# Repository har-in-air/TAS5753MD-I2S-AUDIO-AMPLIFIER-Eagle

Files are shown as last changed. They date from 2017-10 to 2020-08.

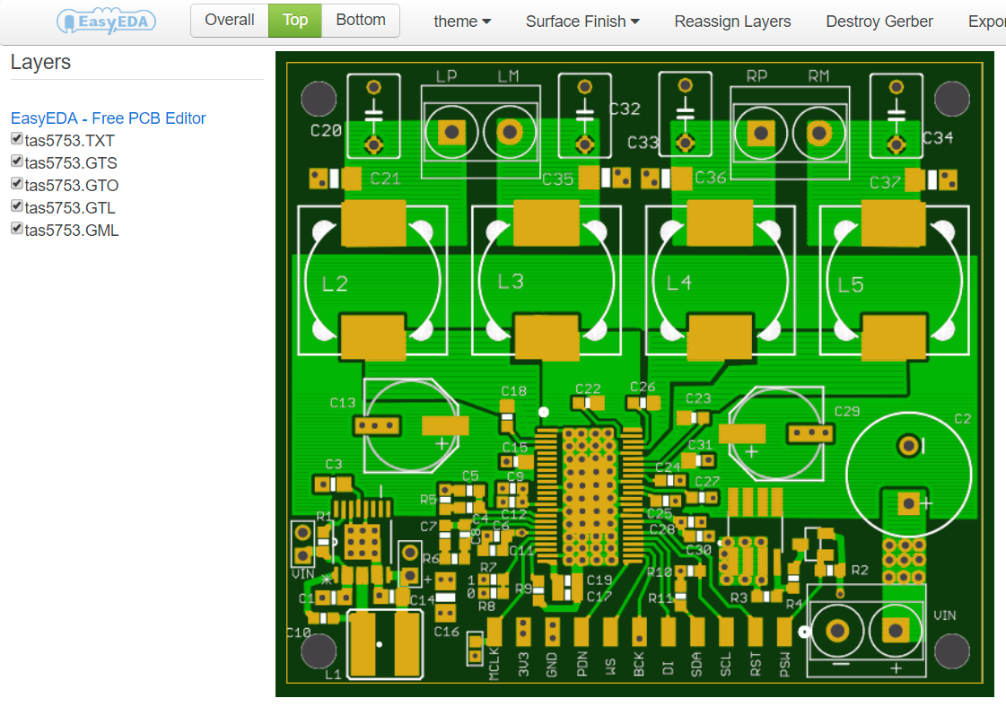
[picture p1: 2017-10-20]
layout_top.png

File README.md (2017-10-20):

# TAS5753MD-I2S-AUDIO-AMPLIFIER-Eagle
Digital audio power amplifier with I2S interface using TI's TAS5753MD chip

Eagle schematic, layout and gerber files

Uses Stereo Bridge Tied Load application schematic from the TI datasheet. Added an A04409 PMOSFET and BSS138 NMOSFET to allow controlled PVDD on/off. Added MAX16904 3.3V (max 600mA) switching regulator to power the TTL logic 3.3V supply - this can also be used to supply 3.3V to the driving circuit, e.g. Espressif ESP32 module with web radio or bluetooth speaker firmware.

Features : 
1. PVDD range is 4.5V to 24V
2. Can drive 4ohm speakers
3. 90% efficiency
4. 0.2%THD @ 10W rms/channel into 4ohms with PVDD = 12V
5. Requires external MCLK. However, if used with 44.1kHz or 48kHz sampling rates, and the bit clock (BCK / SCLK) is at least 64 x sampling rate, then MCLK can be tied to BCK. A solder jumper is provided for this. This is how I have tested the board.

## Components
See the datasheet for recommendations. The specific packages used in the layout are :

### Capacitors

1206 : C16, C21, C35, C36, C37

0805 : C1, C3, C14

0603 : remaining smt ceramic caps

### Resistors
All are 0603 package. R9 (18K) needs to be 1% precision. Either populate R7 OR R8 to set the LSb of the TAS5753MD I2C slave address. R4 (22K) should be shorted or replaced with a 0 ohm resistor if PVDD is less than 10V, to ensure that the PMOSFET fully turns on.

I found all the passive components on Aliexpress and Ebay. E.g.:

https://www.aliexpress.com/item/10pcs-lot-12-12-7-15UH-SMT-SMD-Patch-Shielding-Power-Inductors-150-Electronic-Components-Free/32591194870.html

https://www.aliexpress.com/item/10pcs-0-68uF-684J-100V-Free-shipping-CBB-Polypropylene-film-capacitor-pitch-5mm-684-100V-680nF/32712243979.html

https://www.aliexpress.com/item/100pcs-lot-100nF-X7R-Error-10-50V-0603-smd-capacitor/32318089455.html

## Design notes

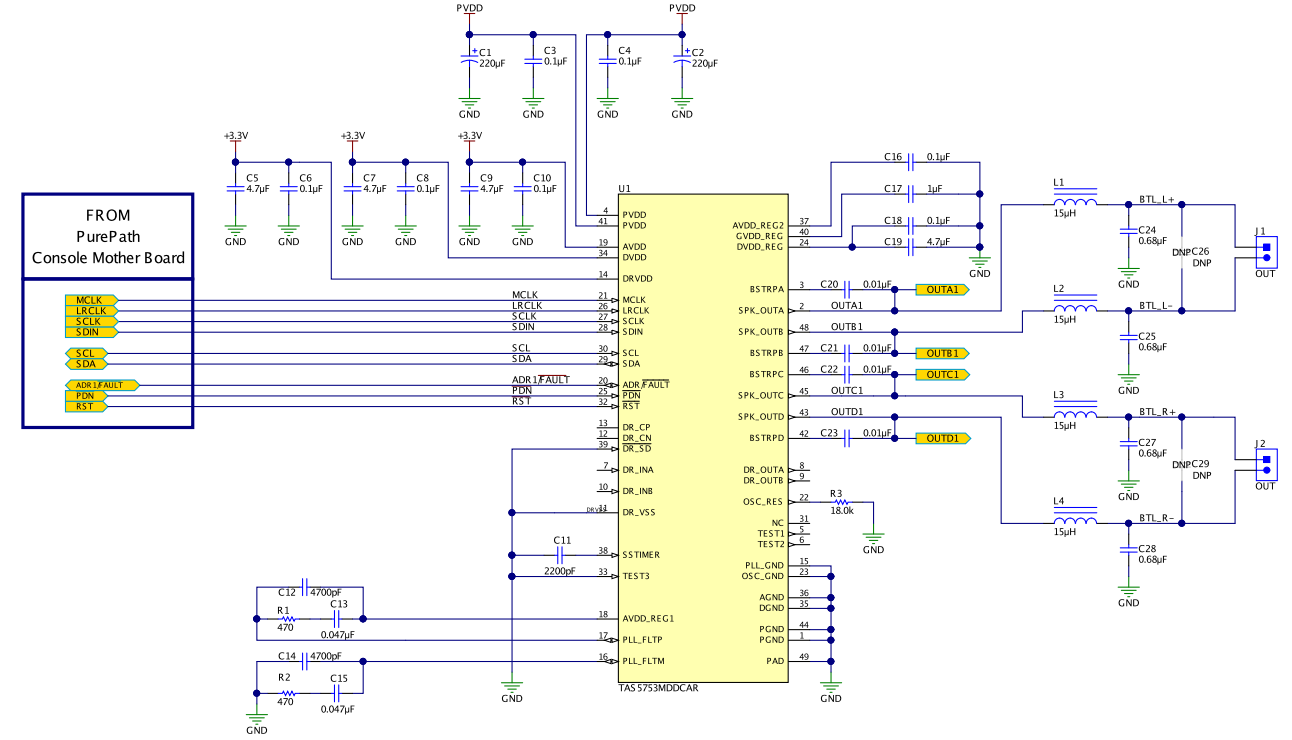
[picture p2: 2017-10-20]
datasheet_schematic.png

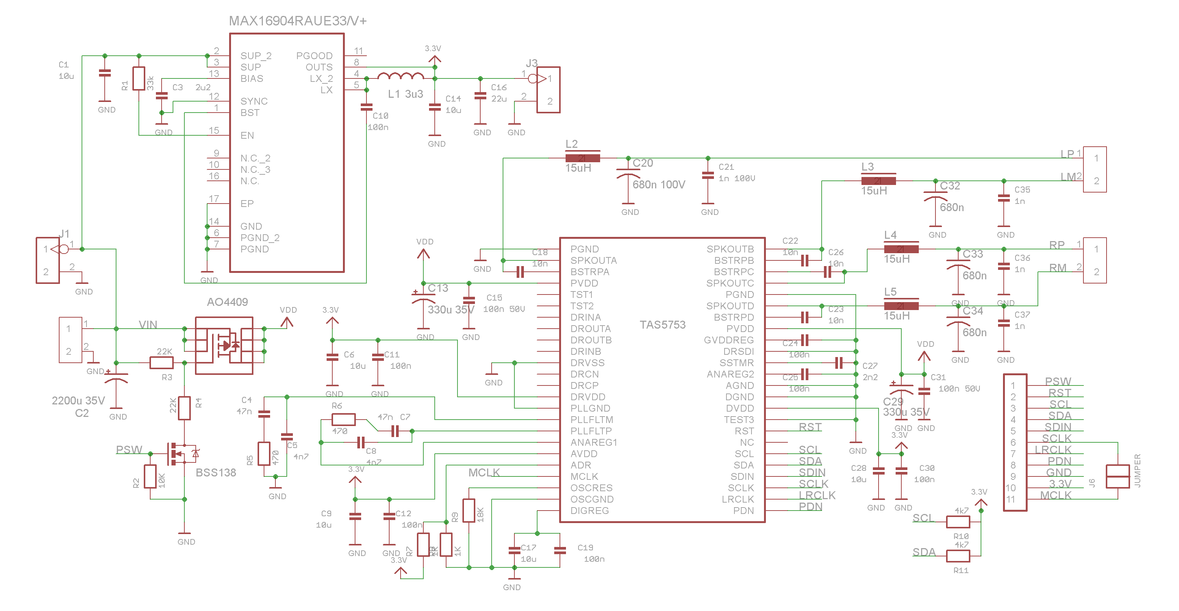
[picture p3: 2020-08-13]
tas5753_schematic.png

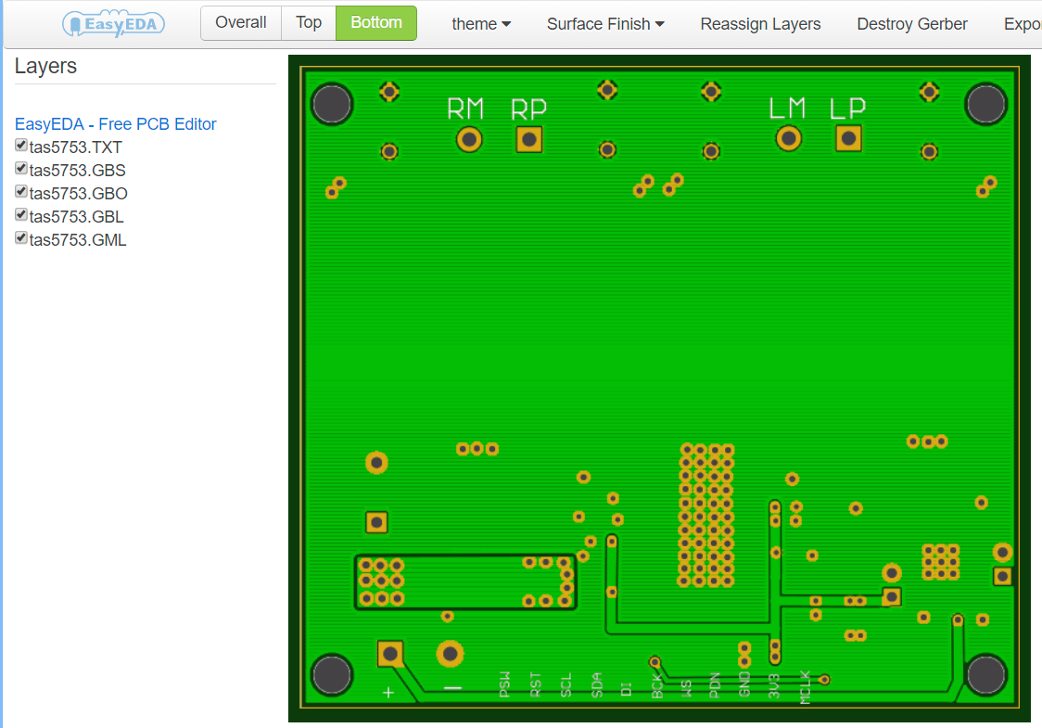
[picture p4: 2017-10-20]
layout_bottom.png

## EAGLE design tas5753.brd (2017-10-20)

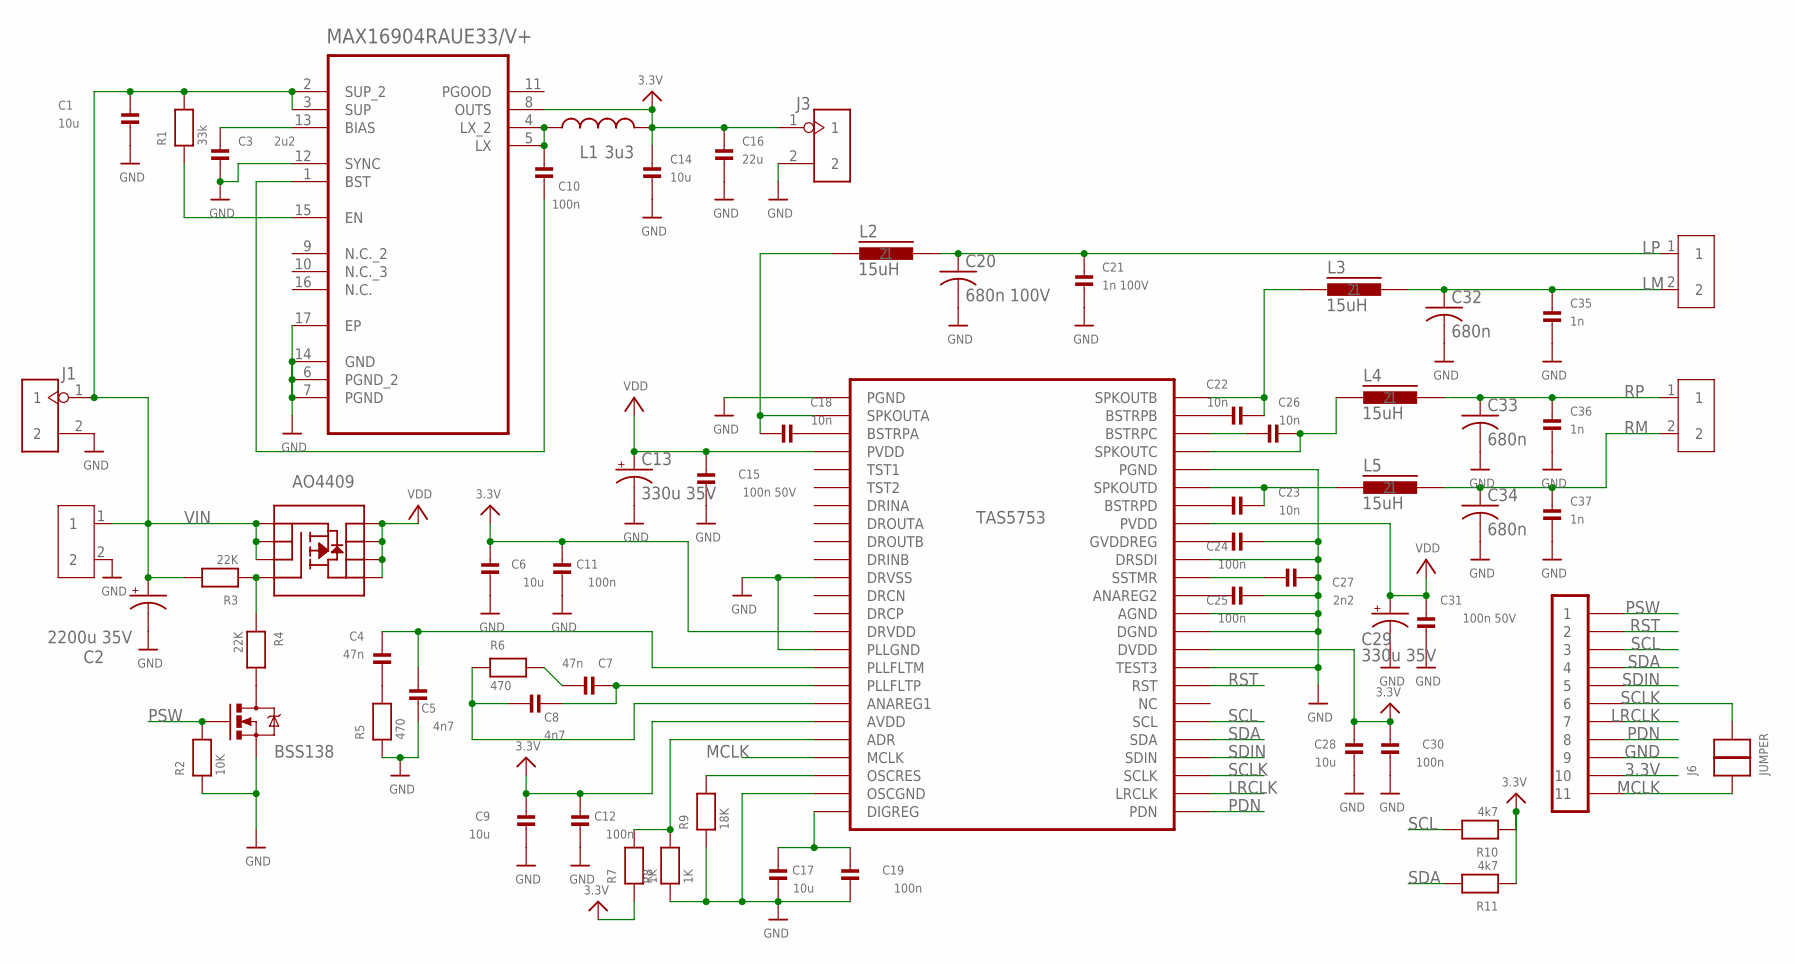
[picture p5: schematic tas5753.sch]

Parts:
C1, C14: 10u; 0805
C2: 2200u 35V; CPOL-RADIAL-1000UF-25V
C3: 2u2; 0805
C4, C7: 47n; 0603
C5, C8: 4n7; 0603
C6, C9, C17, C28: 10u; 0603
C10, C11, C12, C19, C24, C25, C30: 100n; 0603
C13, C29: 330u 35V; PANASONIC_E
C15, C31: 100n 50V; 0603
C16: 22u; 1206
C18, C22, C23, C26: 10n; 0603
C20: 680n 100V; C050-045X075
C21: 1n 100V; 1206
C27: 2n2; 0603
C32, C33, C34: 680n; C050-045X075
C35, C36, C37: 1n; 1206
IC1: AO4409; SO08
J1, J3: HEADER-2P-2.0; 2P-2.0
J2, J4, J5: SCREW-TERMINAL-2P'5.08'; 2P-5.08
J6: JUMPER
L1: 3u3; CR54
L2, L3, L4, L5: 15uH; DR125
P1: CONN_1X11_SMT_254; CONN_SMT_1X11_254
Q1: BSS138; SOT23
R1: 33k; 0603
R2: 10K; 0603
R3, R4: 22K; 0603
R5, R6: 470; 0603
R7, R8: 1K; 0603
R9: 18K; 0603
R10, R11: 4k7; 0603
U1: MAX16904RAUE33/V+; SOP65P638X110-17N
U2: TAS5753; HTSSOP_48

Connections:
3.3V: C6.1, C9.1, C11.1, C12.1, C14.1, C16.1, C28.1, C30.1, J3.1, L1.P$2 (2), P1.P$10 (10), R7.1, R10.1, R11.1, U1.8 (OUTS), U2.P$14 (DRVDD), U2.P$19 (AVDD), U2.P$34 (DVDD)
GND: C1.2, C2.2 (-), C3.2, C5.1, C6.2, C9.2, C11.2, C12.2, C13.-, C14.2, C15.1, C16.2, C17.2, C19.2, C20.2, C21.2, C24.2, C25.2, C27.2, C28.2, C29.-, C30.2, C31.1, C32.2, C33.2, C34.2, C35.2, C36.2, C37.2, J1.2, J2.2, J3.2, P1.P$9 (9), Q1.2 (S), R2.1, R5.1, R8.1, R9.1, U1.6 (PGND_2), U1.7 (PGND), U1.12 (SYNC), U1.14 (GND), U1.17 (EP), U2.P$1 (PGND), U2.P$11 (DRVSS), U2.P$15 (PLLGND), U2.P$23 (OSCGND), U2.P$33 (TEST3), U2.P$35 (DGND), U2.P$36 (AGND), U2.P$39 (DRSDI), U2.P$44 (PGND), U2.P$49 (PGND)
LM: C32.1, C35.1, J4.2, L3.2
LP: C20.1, C21.1, J4.1, L2.2
LRCLK: P1.P$7 (7), U2.P$26 (LRCLK)
MCLK: J6.1, P1.P$11 (11), U2.P$21 (MCLK)
unnamed: R9.2, U2.P$22 (OSCRES)
unnamed: C7.2, R6.2
unnamed: C18.2, U2.P$3 (BSTRPA)
unnamed: C7.1, C8.1, U2.P$17 (PLLFLTP)
unnamed: C26.1, U2.P$46 (BSTRPC)
unnamed: C22.1, U2.P$47 (BSTRPB)
unnamed: C22.2, L3.1, U2.P$48 (SPKOUTB)
unnamed: C26.2, L4.1, U2.P$45 (SPKOUTC)
unnamed: R7.2, R8.2, U2.P$20 (ADR)
unnamed: C4.1, R5.2
unnamed: C18.1, L2.1, U2.P$2 (SPKOUTA)
unnamed: C4.2, C5.2, U2.P$16 (PLLFLTM)
unnamed: C23.1, U2.P$42 (BSTRPD)
unnamed: C23.2, L5.1, U2.P$43 (SPKOUTD)
unnamed: C27.1, U2.P$38 (SSTMR)
unnamed: C25.1, U2.P$37 (ANAREG2)
unnamed: IC1.4 (G), R3.1, R4.1
unnamed: C24.1, U2.P$40 (GVDDREG)
unnamed: C10.1, L1.P$1 (1), U1.4 (LX_2), U1.5 (LX)
unnamed: C10.2, U1.1 (BST)
unnamed: C8.2, R6.1, U2.P$18 (ANAREG1)
unnamed: C3.1, U1.13 (BIAS)
unnamed: R1.1, U1.15 (EN)
unnamed: C17.1, C19.1, U2.P$24 (DIGREG)
unnamed: Q1.3 (D), R4.2
PDN: P1.P$8 (8), U2.P$25 (PDN)
PSW: P1.P$1 (1), Q1.1 (G), R2.2
RM: C34.1, C37.1, J5.2, L5.2
RP: C33.1, C36.1, J5.1, L4.2
RST: P1.P$2 (2), U2.P$32 (RST)
SCL: P1.P$3 (3), R10.2, U2.P$30 (SCL)
SCLK: J6.2, P1.P$6 (6), U2.P$27 (SCLK)
SDA: P1.P$4 (4), R11.2, U2.P$29 (SDA)
SDIN: P1.P$5 (5), U2.P$28 (SDIN)
VDD: C13.+, C15.2, C29.+, C31.2, IC1.5 (D), IC1.6 (D), IC1.7 (D), IC1.8 (D), U2.P$4 (PVDD), U2.P$41 (PVDD)
VIN: C1.1, C2.1 (+), IC1.1 (S), IC1.2 (S), IC1.3 (S), J1.1, J2.1, R1.2, R3.2, U1.2 (SUP_2), U1.3 (SUP)

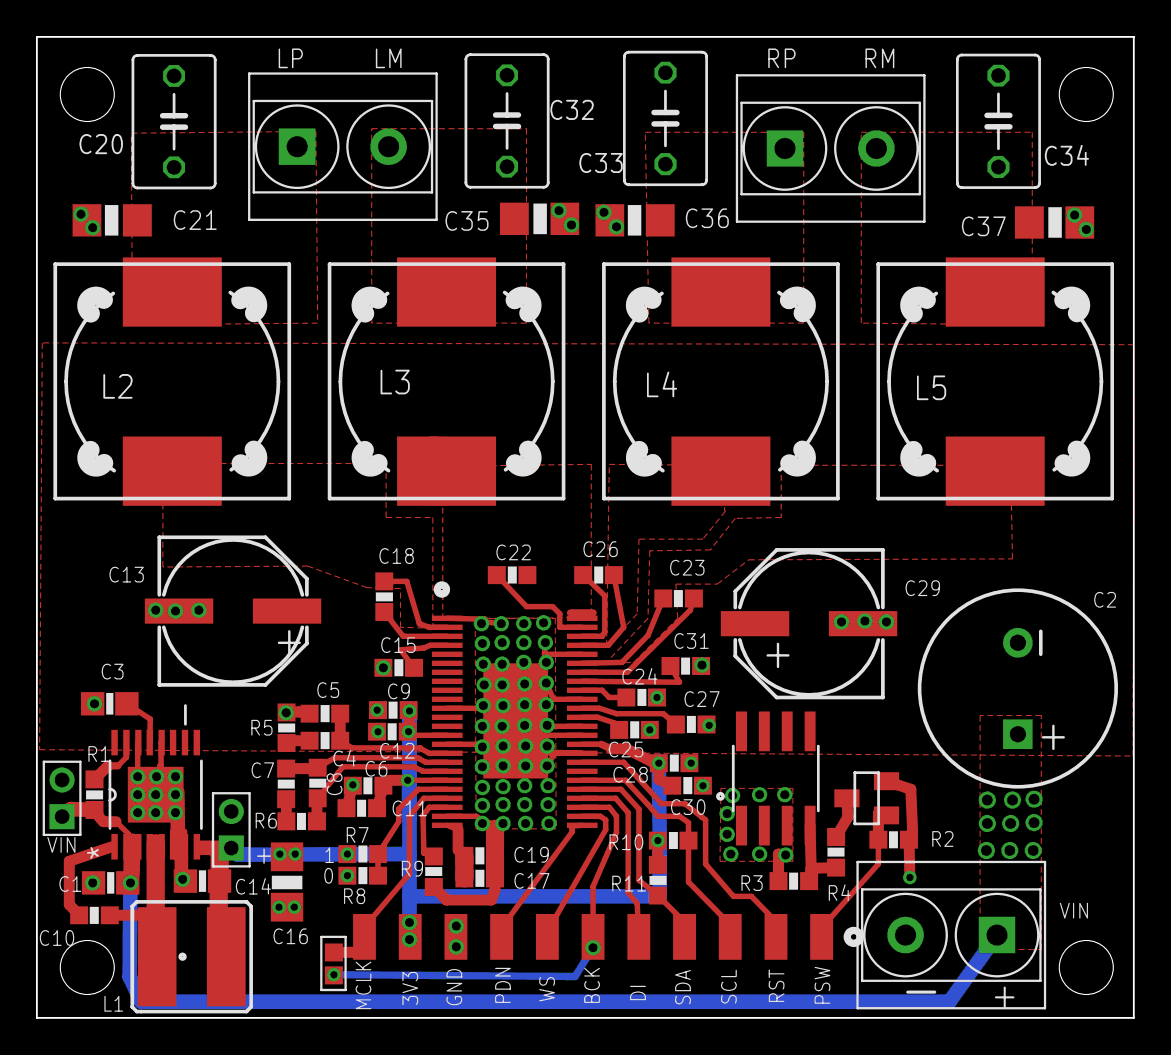
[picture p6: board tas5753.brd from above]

Board: 2 copper layers, 60.9 x 54.5 mm, 64 parts (0 on the bottom side), 42 nets.

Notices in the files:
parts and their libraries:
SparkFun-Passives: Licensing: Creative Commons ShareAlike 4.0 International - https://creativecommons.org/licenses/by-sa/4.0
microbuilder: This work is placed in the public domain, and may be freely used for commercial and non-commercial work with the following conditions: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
